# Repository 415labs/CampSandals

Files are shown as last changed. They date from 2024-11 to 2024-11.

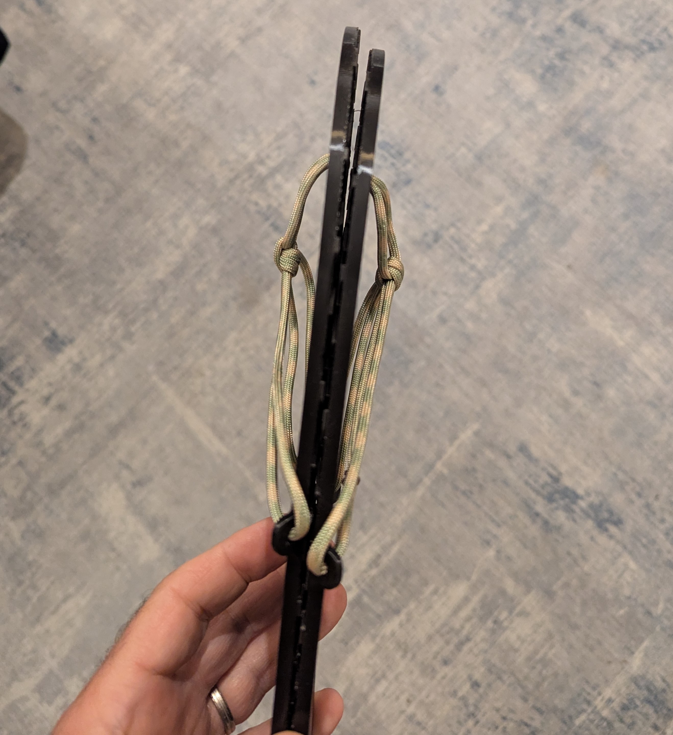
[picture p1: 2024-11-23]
Photos/415Labs-Lightweight backpacking camp shoes-photo8.jpg

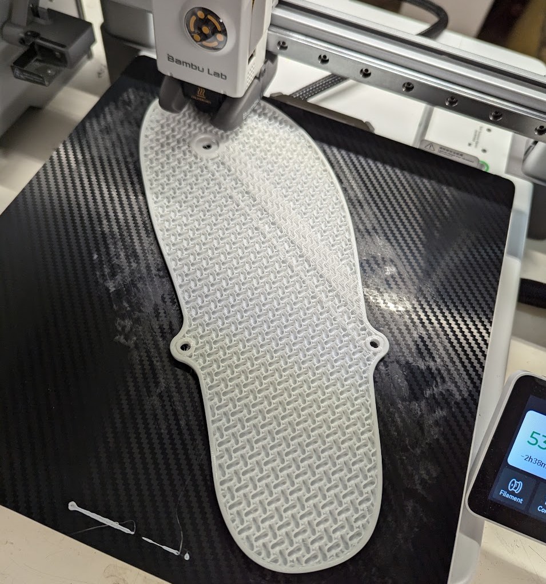
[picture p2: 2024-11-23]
Photos/415Labs-Lightweight backpacking camp shoes-photo1.jpg

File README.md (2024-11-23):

Lightweight sandals for ultralight backpacking (3D printed lightweight sandals)

I've tried a few different commercially-available lightweight sandals, but I found them to be either too bulky, too heavy, or just not comfortable enough. So, I decided to design my own - and share with the community.
These sandals are designed to be:
- (Ultra)light: Weighing in at a mere 80 grams each, you can make them even lighter by reducing the infill and/or top/bottom layers.
- Packable: Super flat (11mm thick) for easy storage in your pack
- Comfortable: A barefoot feel with a comfortable, flexible design.
- Durable: Made from TPU filament for comfort and long-lasting use.
- Superior grip: the sole includes an aggressive tread pattern to provide traction on challenging terrain.
- Best of all, they're completely free to download and print at home: here or https://makerworld.com/en/models/797936#profileId-737339
- Note: This design is sized for a US Men's size 9 shoe. You can easily scale it up or down to fit your size using your slicer software.

Bill of materials
- Filament: Siraya Tech Flex TPU Filament - 85A Shore		https://www.amazon.com/dp/B0CP213ZMG?ref=ppx_yo2ov_dt_b_fed_asin_title&th=1
- Paracord: Paracord 550 (diameter: 4mm)
- Washers (x2): metal, 9/16 OD; 1/4 ID (metric: 14mm OD; 7MM ID)

Printing parameters
- Walls: 4
- Fill: 11%, Gyroid (increase fill for more strengths, at the expense of weight)
- Enable supports (normal, snug)
- Layer height: 0.2mm
- Bottom/Top shell layers: 3		

Assembly:
Prepare the Front Strap:
- Cut a 100mm length of paracord.
- Thread both ends through the front hole of the sandal.
- Slide a washer onto the paracord from the sole side.
- Heat both ends of the paracord with a lighter or heat gun.
- Flatten the heated ends onto the washer using a flat metal tool (ruler). Be cautious to avoid burns.

Create the Side Strap:
- Cut a 520mm length of paracord.
- Thread both ends through side attachment points.
- Tie a knot to secure the strap (Refer to the included photos for a visual guide.)
- Heat both ends of the paracord.
- Join the heated ends together to close the loop. Again, be careful not to burn yourself.

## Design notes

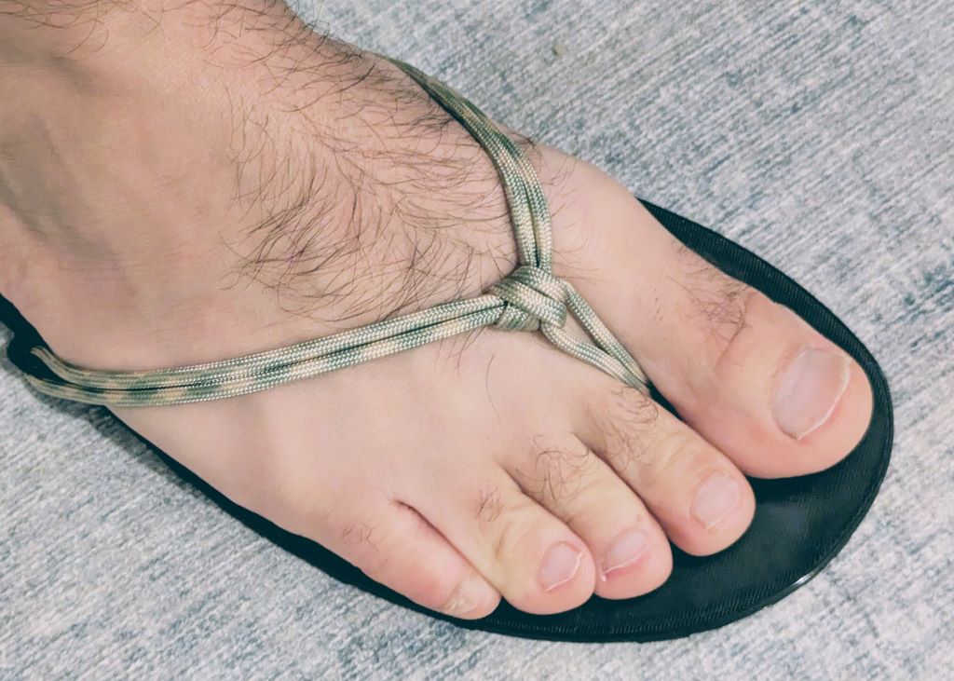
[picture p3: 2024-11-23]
Photos/415Labs-Lightweight backpacking camp shoes-photo6.jpg

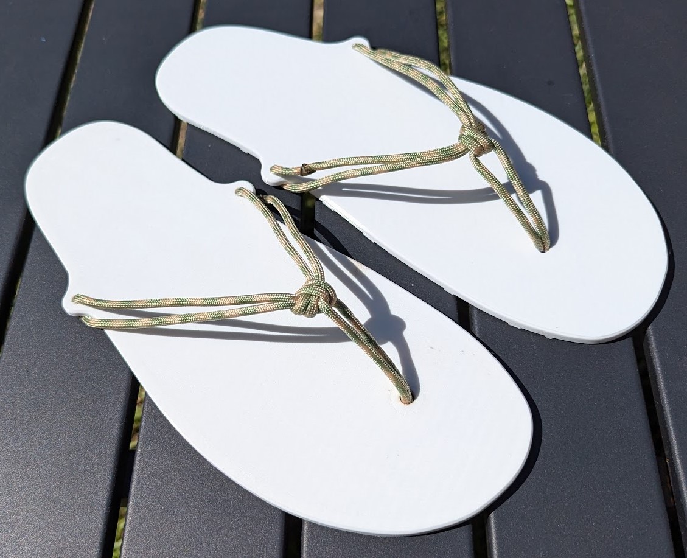
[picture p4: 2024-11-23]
Photos/415Labs-Lightweight backpacking camp shoes-photo5.jpg

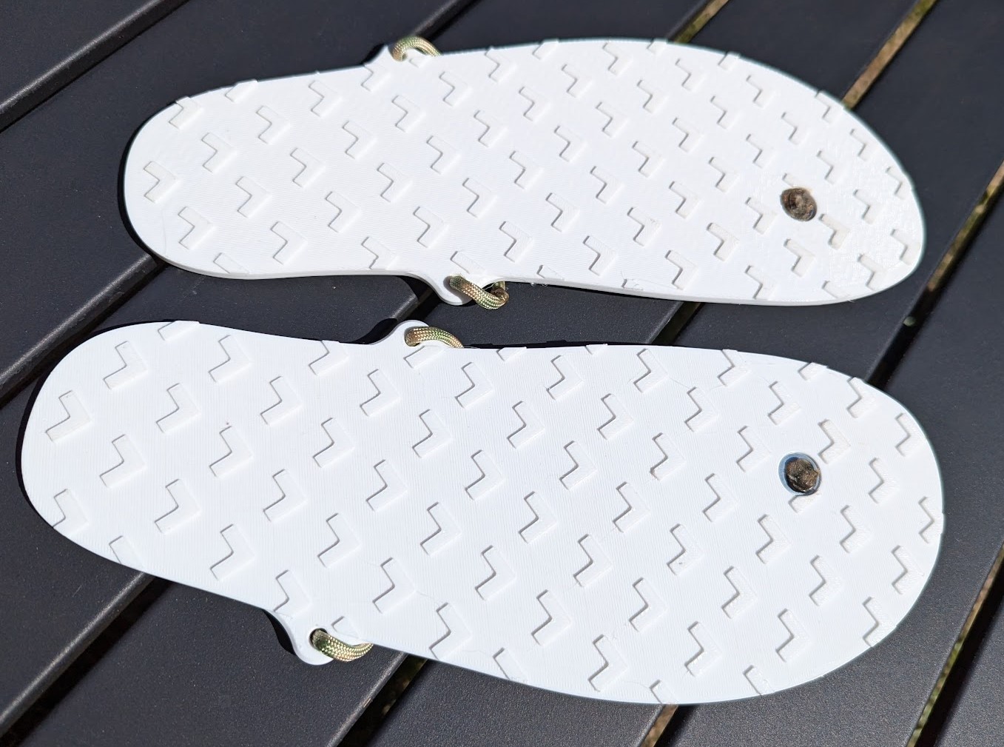
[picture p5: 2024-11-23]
Photos/415Labs-Lightweight backpacking camp shoes-photo3.jpg

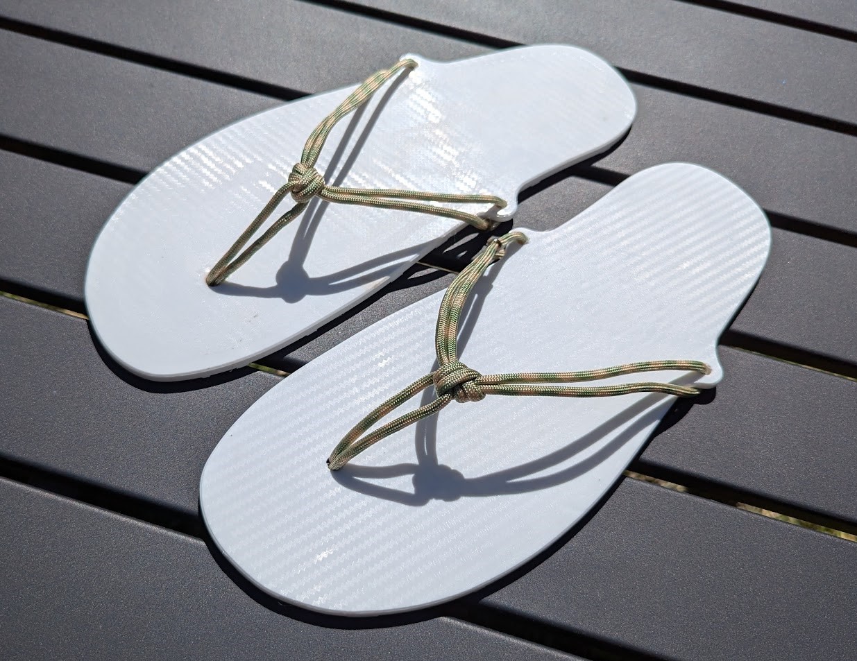
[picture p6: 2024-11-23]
Photos/415Labs-Lightweight backpacking camp shoes-photo4.jpg

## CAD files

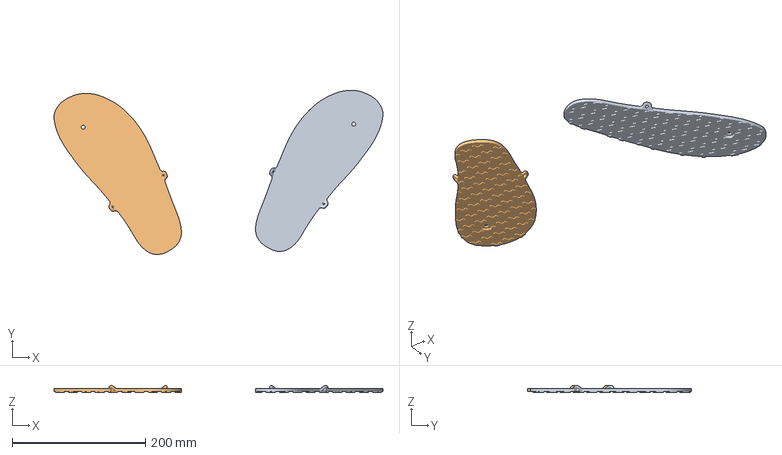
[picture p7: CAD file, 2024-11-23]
Manufacturing/LW backpacking camp shoes-sz9-415Labs.3mf
494.5 x 246.5 x 10.2 mm
LW backpacking camp shoes-sz9-415Labs-RIGHT.STL x 2

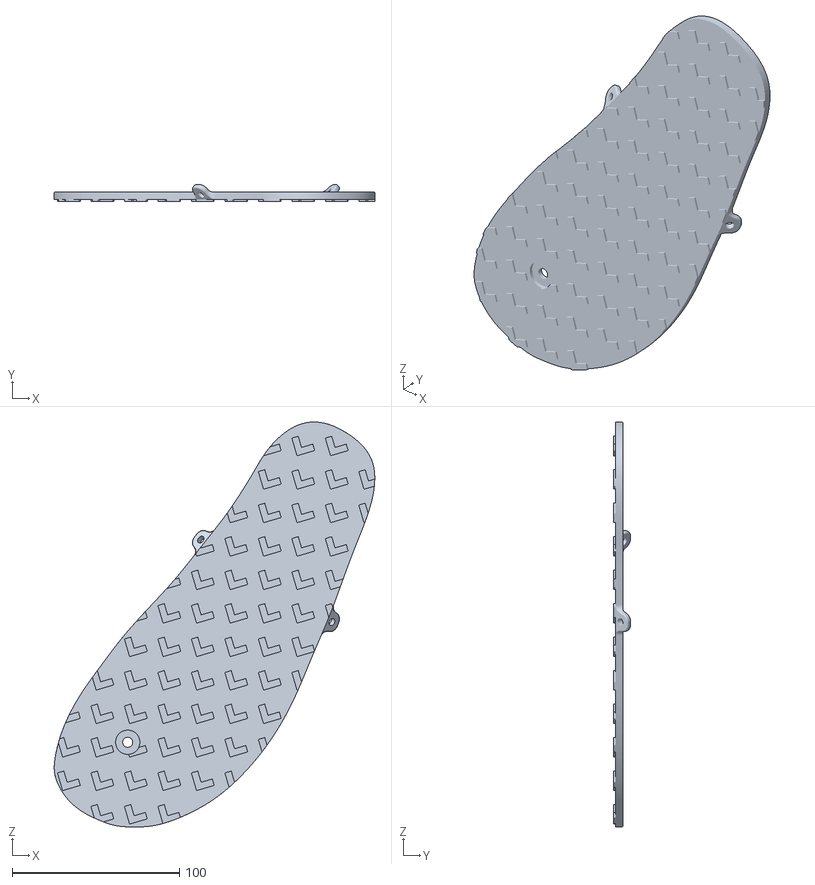
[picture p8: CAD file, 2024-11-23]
Manufacturing/LW backpacking camp shoes-sz9-415Labs-RIGHT.STL
191.5 x 10.2 x 241.9
